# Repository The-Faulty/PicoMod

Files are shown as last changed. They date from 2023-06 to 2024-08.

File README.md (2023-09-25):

# PicoMod
PicoMod is an RP2040-based compute module with high density connectors allowing for its small 20mmx20mm form-factor.

# PicoMod Breakout
This is a breakout for PicoMod to allowing use on a standard breadboard.

# PicoMod Eject
Eject is the evolution of [Lyra](https://github.com/The_Faulty/Lyra) maintaining Lyra's small size while greatly improving the power and sensing abilities. Not only can eject ignite an e-match at apogee, it also contains a 9-DOF sensor suite and two servo outputs enabling TVC (thrust vector control) usage.

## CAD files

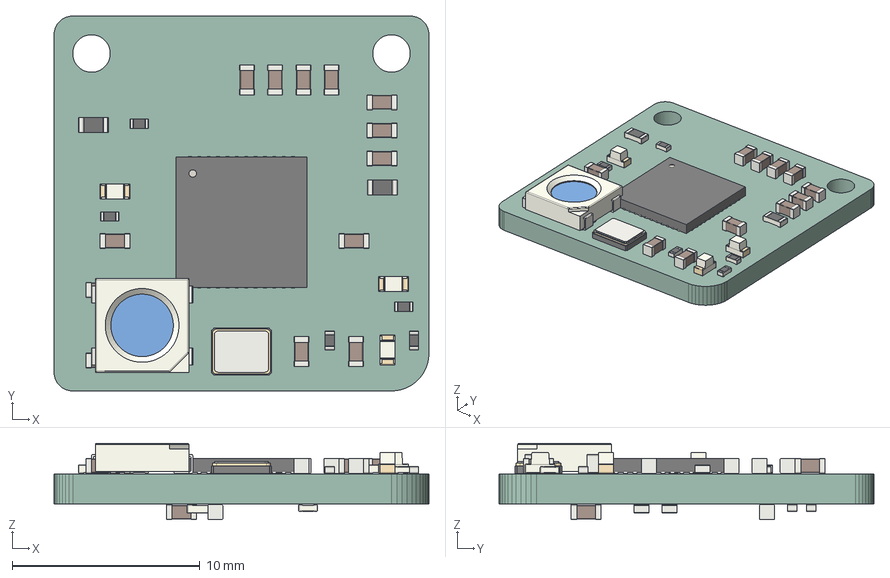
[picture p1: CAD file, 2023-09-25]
PicoMod Core/PicoMod.step
20.0 x 20.0 x 4.08 mm
PicoMod PCB

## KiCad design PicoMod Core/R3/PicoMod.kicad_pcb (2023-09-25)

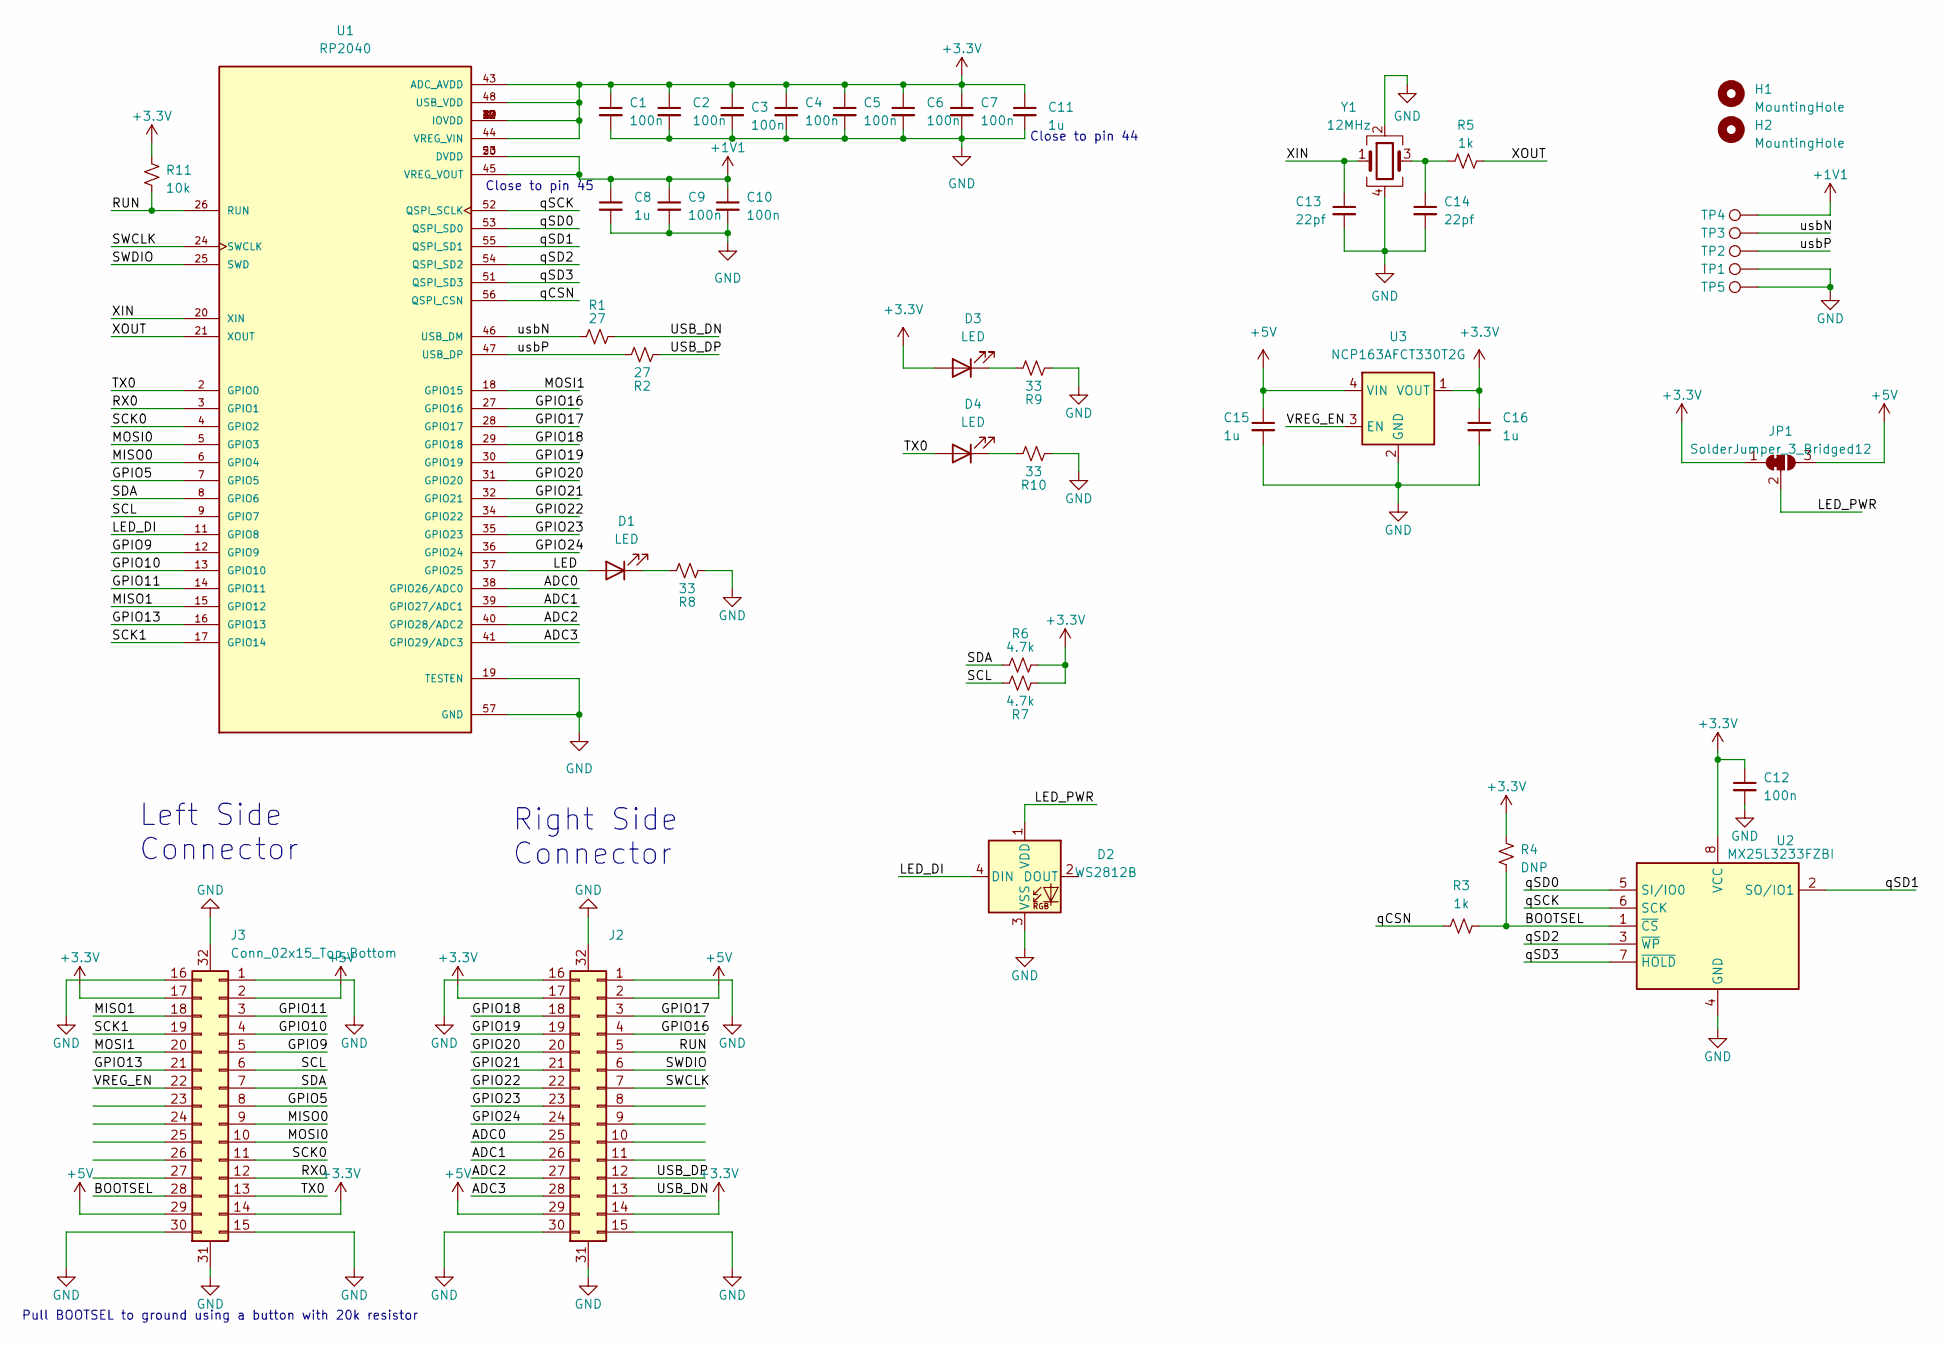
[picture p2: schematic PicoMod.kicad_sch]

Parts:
C1, C2, C3, C4, C5, C6, C7, C9, C10, C12: 100n; C_0603_1608Metric
C8, C11, C15, C16: 1u; C_0603_1608Metric
C13, C14: 22pf; C_0603_1608Metric
D1, D3, D4: LED; LED_0603_1608Metric
D2: WS2812B; LED_WS2812B_PLCC4_2.0x2.0mm_P0.4mm
H1, H2: MountingHole; MountingHole_2mm_M2
J2, J3: Conn_02x15_Top_Bottom; TE-3-2363962-0_30x0.4mm_Plug
JP1: SolderJumper_3_Bridged12; SolderJumper-3_P1.3mm_Open_RoundedPad1.0x1.5mm
R1, R2: 27; R_0402_1005Metric
R3, R5: 1k; R_0402_1005Metric
R4: DNP; R_0603_1608Metric
R6, R7: 4.7k; R_0603_1608Metric
R8, R9, R10: 33; R_0402_1005Metric
R11: 10k; R_0603_1608Metric
TP1: TestPoint; TestPoint_Loop_1.6x0.8mm
TP2, TP3, TP4, TP5: TestPoint; TestPoint_Pad_D1.0mm
U1: RP2040; QFN40P700X700X90-57N; PARTREV 1.6.1
U2: MX25L3233FZBI; SON80P400X300X60-10N
U3: NCP163AFCT330T2G; OnSemi_XDFN4-1EP_1.0x1.0mm_EP0.52x0.52mm
Y1: 12MHz; Crystal_SMD_SeikoEpson_TSX3225-4Pin_3.2x2.5mm

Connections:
+1V1: C8.1, C9.1, C10.1, TP4.1, U1.23 (DVDD), U1.45 (VREG_VOUT), U1.50 (DVDD)
+3V3: C1.1, C2.1, C3.1, C4.1, C5.1, C6.1, C7.1, C11.1, C12.1, C16.1, D3.2 (A), J2.14, J2.17, J3.14, J3.17, JP1.1 (A), R4.2, R6.2, R7.2, R11.2, U1.1 (IOVDD), U1.10 (IOVDD), U1.22 (IOVDD), U1.33 (IOVDD), U1.42 (IOVDD), U1.43 (ADC_AVDD), U1.44 (VREG_VIN), U1.48 (USB_VDD), U1.49 (IOVDD), U2.8 (VCC), U3.1 (VOUT)
+5V: C15.1, J2.2, J2.29, J3.2, J3.29, JP1.3 (B), U3.4 (VIN)
/ADC0: J2.25, U1.38 (GPIO26/ADC0)
/ADC1: J2.26, U1.39 (GPIO27/ADC1)
/ADC2: J2.27, U1.40 (GPIO28/ADC2)
/ADC3: J2.28, U1.41 (GPIO29/ADC3)
/BOOTSEL: J3.28, R3.2, R4.1, U2.1 (~CS)
/GPIO5: J3.8, U1.7 (GPIO5)
/GPIO9: J3.5, U1.12 (GPIO9)
/GPIO10: J3.4, U1.13 (GPIO10)
/GPIO11: J3.3, U1.14 (GPIO11)
/GPIO13: J3.21, U1.16 (GPIO13)
/GPIO16: J2.4, U1.27 (GPIO16)
/GPIO17: J2.3, U1.28 (GPIO17)
/GPIO18: J2.18, U1.29 (GPIO18)
/GPIO19: J2.19, U1.30 (GPIO19)
/GPIO20: J2.20, U1.31 (GPIO20)
/GPIO21: J2.21, U1.32 (GPIO21)
/GPIO22: J2.22, U1.34 (GPIO22)
/GPIO23: J2.23, U1.35 (GPIO23)
/GPIO24: J2.24, U1.36 (GPIO24)
/LED: D1.2 (A), U1.37 (GPIO25)
/LED_DI: D2.4 (DIN), U1.11 (GPIO8)
/LED_PWR: D2.1 (VDD), JP1.2 (C)
/MISO0: J3.9, U1.6 (GPIO4)
/MISO1: J3.18, U1.15 (GPIO12)
/MOSI0: J3.10, U1.5 (GPIO3)
/MOSI1: J3.20, U1.18 (GPIO15)
/RUN: J2.5, R11.1, U1.26 (RUN)
/RX0: J3.12, U1.3 (GPIO1)
/SCK0: J3.11, U1.4 (GPIO2)
/SCK1: J3.19, U1.17 (GPIO14)
/SCL: J3.6, R7.1, U1.9 (GPIO7)
/SDA: J3.7, R6.1, U1.8 (GPIO6)
/SWCLK: J2.7, U1.24 (SWCLK)
/SWDIO: J2.6, U1.25 (SWD)
/TX0: D4.2 (A), J3.13, U1.2 (GPIO0)
/USB_DN: J2.13, R1.2
/USB_DP: J2.12, R2.2
/VREG_EN: J3.22, U3.3 (EN)
/XIN: C13.1, U1.20 (XIN), Y1.1
/XOUT: R5.1, U1.21 (XOUT)
/qCSN: R3.1, U1.56 (QSPI_CSN)
/qSCK: U1.52 (QSPI_SCLK), U2.6 (SCK)
/qSD0: U1.53 (QSPI_SD0), U2.5 (SI/IO0)
/qSD1: U1.55 (QSPI_SD1), U2.2 (SO/IO1)
/qSD2: U1.54 (QSPI_SD2), U2.3 (~WP)
/qSD3: U1.51 (QSPI_SD3), U2.7 (~HOLD)
/usbN: R1.1, TP3.1, U1.46 (USB_DM)
/usbP: R2.1, TP2.1, U1.47 (USB_DP)
GND: C1.2, C2.2, C3.2, C4.2, C5.2, C6.2, C7.2, C8.2, C9.2, C10.2, C11.2, C12.2, C13.2, C14.2, C15.2, C16.2, D2.3 (VSS), J2.1, J2.15, J2.16, J2.30, J2.31 (Pin_30), J2.32 (Pin_30), J3.1, J3.15, J3.16, J3.30, J3.31 (Pin_30), J3.32 (Pin_30), R8.2, R9.2, R10.2, TP1.1, TP5.1, U1.19 (TESTEN), U1.57 (GND), U2.4 (GND), U3.2 (GND), Y1.2, Y1.4
unnamed: C14.1, R5.2, Y1.3
unnamed: D1.1 (K), R8.1
unnamed: D3.1 (K), R9.1
unnamed: D4.1 (K), R10.1

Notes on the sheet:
Close to pin 45
Left Side Connector
Close to pin 44
Right Side Connector
Pull BOOTSEL to ground using a button with 20k resistor

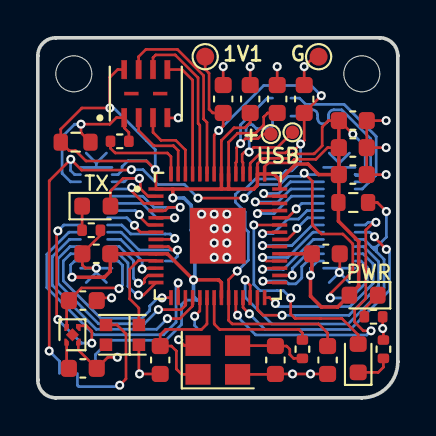
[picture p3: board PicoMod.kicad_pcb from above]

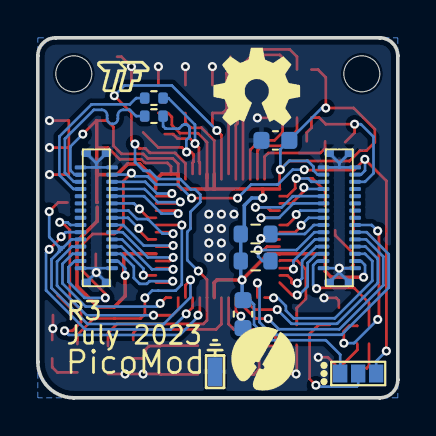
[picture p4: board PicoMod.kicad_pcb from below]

Board: 2 copper layers, 20.0 x 20.0 mm, 45 parts (10 on the bottom side), 56 nets.

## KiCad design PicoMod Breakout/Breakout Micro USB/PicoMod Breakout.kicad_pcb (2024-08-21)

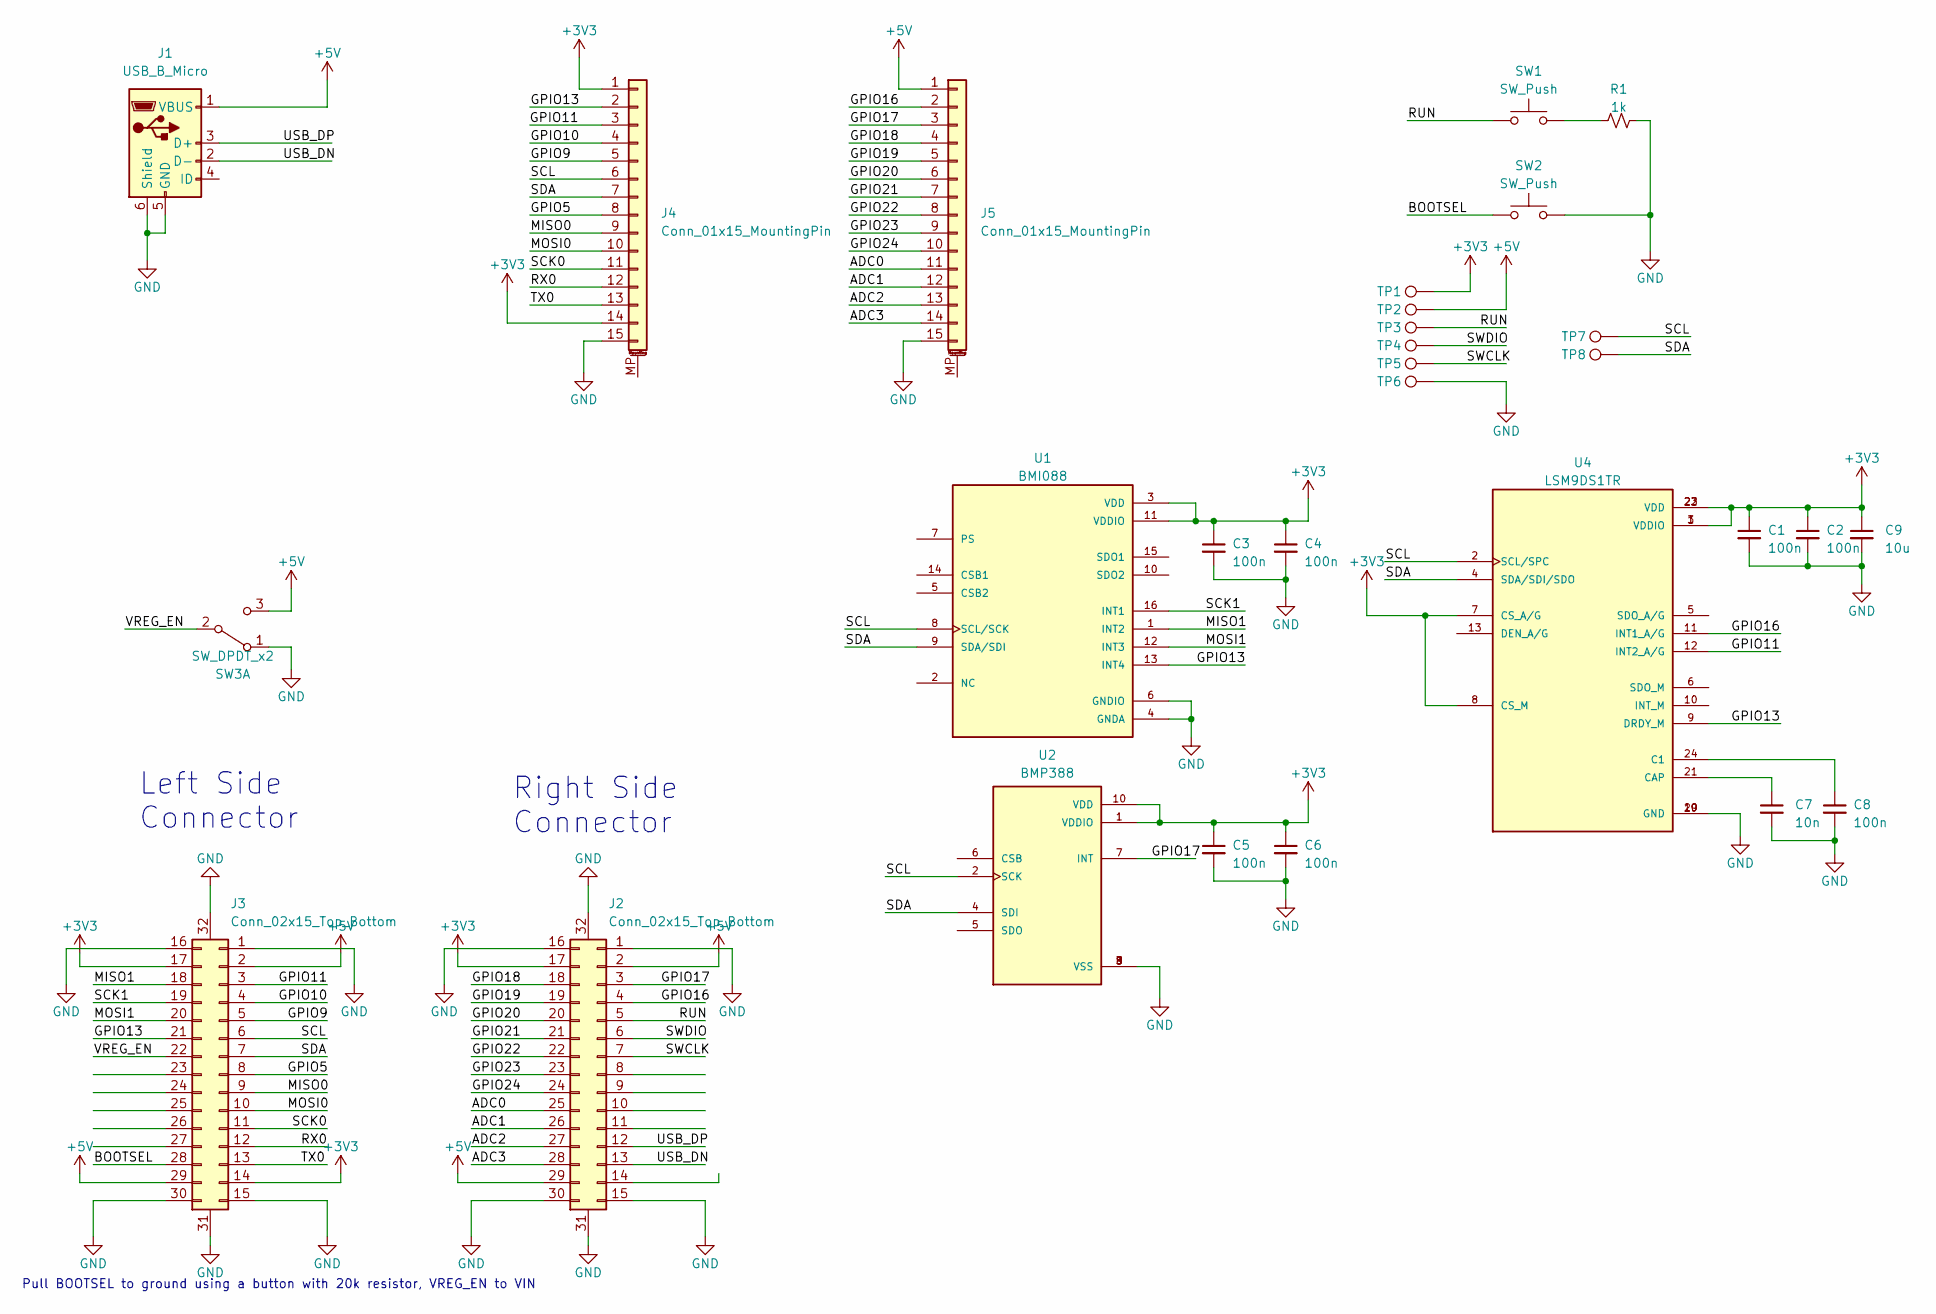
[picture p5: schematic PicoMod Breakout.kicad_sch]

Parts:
C1, C2, C3, C4, C5, C6, C8: 100n; C_0603_1608Metric
C7: 10n; C_0603_1608Metric
C9: 10u; C_0603_1608Metric
J1: USB_B_Micro; USB_Micro-B_Amphenol_10104110_Horizontal
J2, J3: Conn_02x15_Top_Bottom; TE-3-2363962-0_30x0.4mm_Recepticle
J4, J5: Conn_01x15_MountingPin; PinSocket_1x15_P2.54mm_Vertical
R1: 1k; R_0603_1608Metric_Pad0.98x0.95mm_HandSolder
SW1, SW2: SW_Push; PTS815 SJM 250
SW3: SW_DPDT_x2; SPDT_Switch_AYZ0102AGRLC
TP1, TP2, TP3, TP4, TP5, TP6, TP7, TP8: TestPoint; TestPoint_Loop_1.6x0.8mm
U1: BMI088; PQFN50P450X300X100-16N
U2: BMP388; PQFN50P200X200X80-10N; PARTREV 1.1
U4: LSM9DS1TR; PQFN43P300X350X102-24N; PARTREV 3

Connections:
+3V3: C1.1, C2.1, C3.1, C4.1, C5.1, C6.1, C9.1, J2.17, J3.14, J3.17, J4.1, J4.14, TP1.1, U1.3 (VDD), U1.11 (VDDIO), U2.1 (VDDIO), U2.10 (VDD), U4.1 (VDDIO), U4.3 (VDDIO), U4.7 (CS_A/G), U4.8 (CS_M), U4.22 (VDD), U4.23 (VDD)
+5V: J1.1 (VBUS), J2.2, J2.29, J3.2, J3.29, J5.1, SW3.3 (C), TP2.1
/ADC0: J2.25, J5.11
/ADC1: J2.26, J5.12
/ADC2: J2.27, J5.13
/ADC3: J2.28, J5.14
/BOOTSEL: J3.28, SW2.1
/GPIO5: J3.8, J4.8
/GPIO9: J3.5, J4.5
/GPIO10: J3.4, J4.4
/GPIO11: J3.3, J4.3, U4.12 (INT2_A/G)
/GPIO13: J3.21, J4.2, U1.13 (INT4), U4.9 (DRDY_M)
/GPIO16: J2.4, J5.2, U4.11 (INT1_A/G)
/GPIO17: J2.3, J5.3, U2.7 (INT)
/GPIO18: J2.18, J5.4
/GPIO19: J2.19, J5.5
/GPIO20: J2.20, J5.6
/GPIO21: J2.21, J5.7
/GPIO22: J2.22, J5.8
/GPIO23: J2.23, J5.9
/GPIO24: J2.24, J5.10
/MISO0: J3.9, J4.9
/MISO1: J3.18, U1.1 (INT2)
/MOSI0: J3.10, J4.10
/MOSI1: J3.20, U1.12 (INT3)
/RUN: J2.5, SW1.1, TP3.1
/RX0: J3.12, J4.12
/SCK0: J3.11, J4.11
/SCK1: J3.19, U1.16 (INT1)
/SCL: J3.6, J4.6, TP7.1, U1.8 (SCL/SCK), U2.2 (SCK), U4.2 (SCL/SPC)
/SDA: J3.7, J4.7, TP8.1, U1.9 (SDA/SDI), U2.4 (SDI), U4.4 (SDA/SDI/SDO)
/SWCLK: J2.7, TP5.1
/SWDIO: J2.6, TP4.1
/TX0: J3.13, J4.13
/USB_DN: J1.2 (D-), J2.13
/USB_DP: J1.3 (D+), J2.12
/VREG_EN: J3.22, SW3.2 (B)
GND: C1.2, C2.2, C3.2, C4.2, C5.2, C6.2, C7.2, C8.2, C9.2, J1.5 (GND), J1.6 (Shield), J2.1, J2.15, J2.16, J2.30, J2.31 (Pin_30), J2.32 (Pin_30), J3.1, J3.15, J3.16, J3.30, J3.31 (Pin_30), J3.32 (Pin_30), J4.15, J5.15, R1.2, SW2.2, SW3.1 (A), TP6.1, U1.4 (GNDA), U1.6 (GNDIO), U2.3 (VSS), U2.8 (VSS), U2.9 (VSS), U4.19 (GND), U4.20 (GND)
unnamed: R1.1, SW1.2
unnamed: C8.1, U4.24 (C1)
unnamed: C7.1, U4.21 (CAP)

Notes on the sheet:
Left Side Connector
Right Side Connector
Pull BOOTSEL to ground using a button with 20k resistor, VREG_EN to VIN

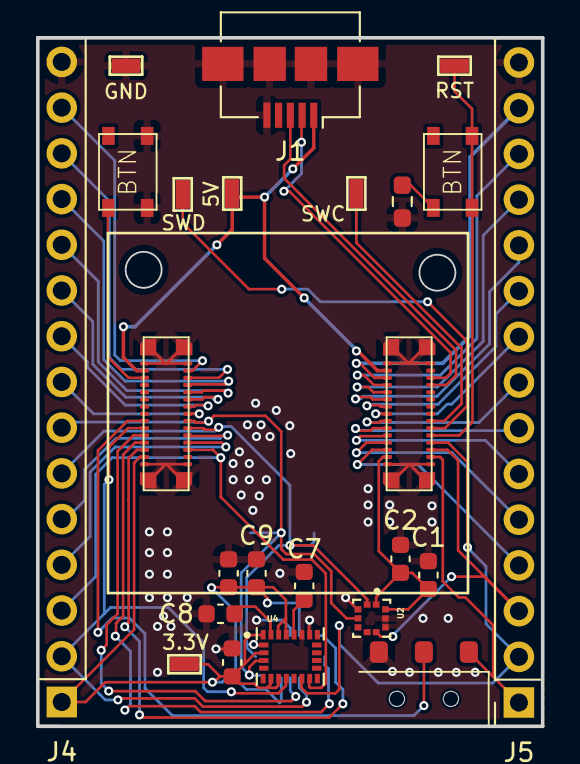
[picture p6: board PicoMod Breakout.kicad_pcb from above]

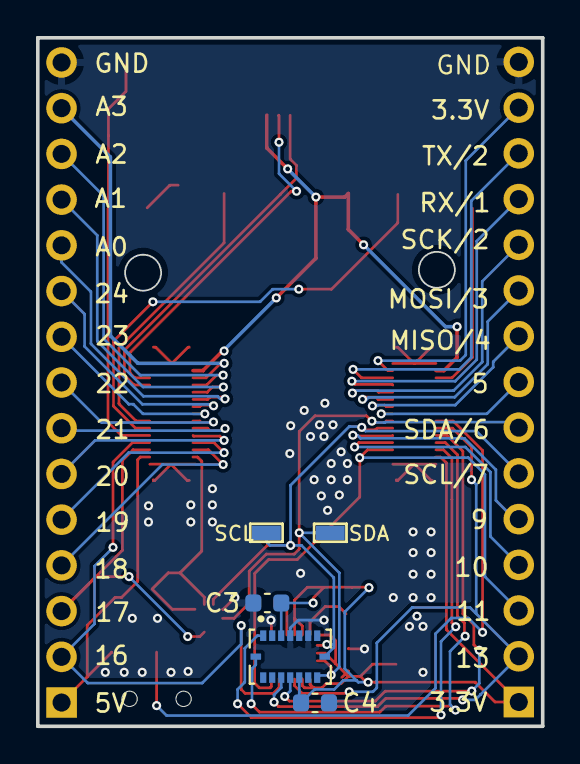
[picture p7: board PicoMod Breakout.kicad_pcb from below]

Board: 2 copper layers, 28.0 x 38.3 mm, 29 parts (5 on the bottom side), 41 nets.

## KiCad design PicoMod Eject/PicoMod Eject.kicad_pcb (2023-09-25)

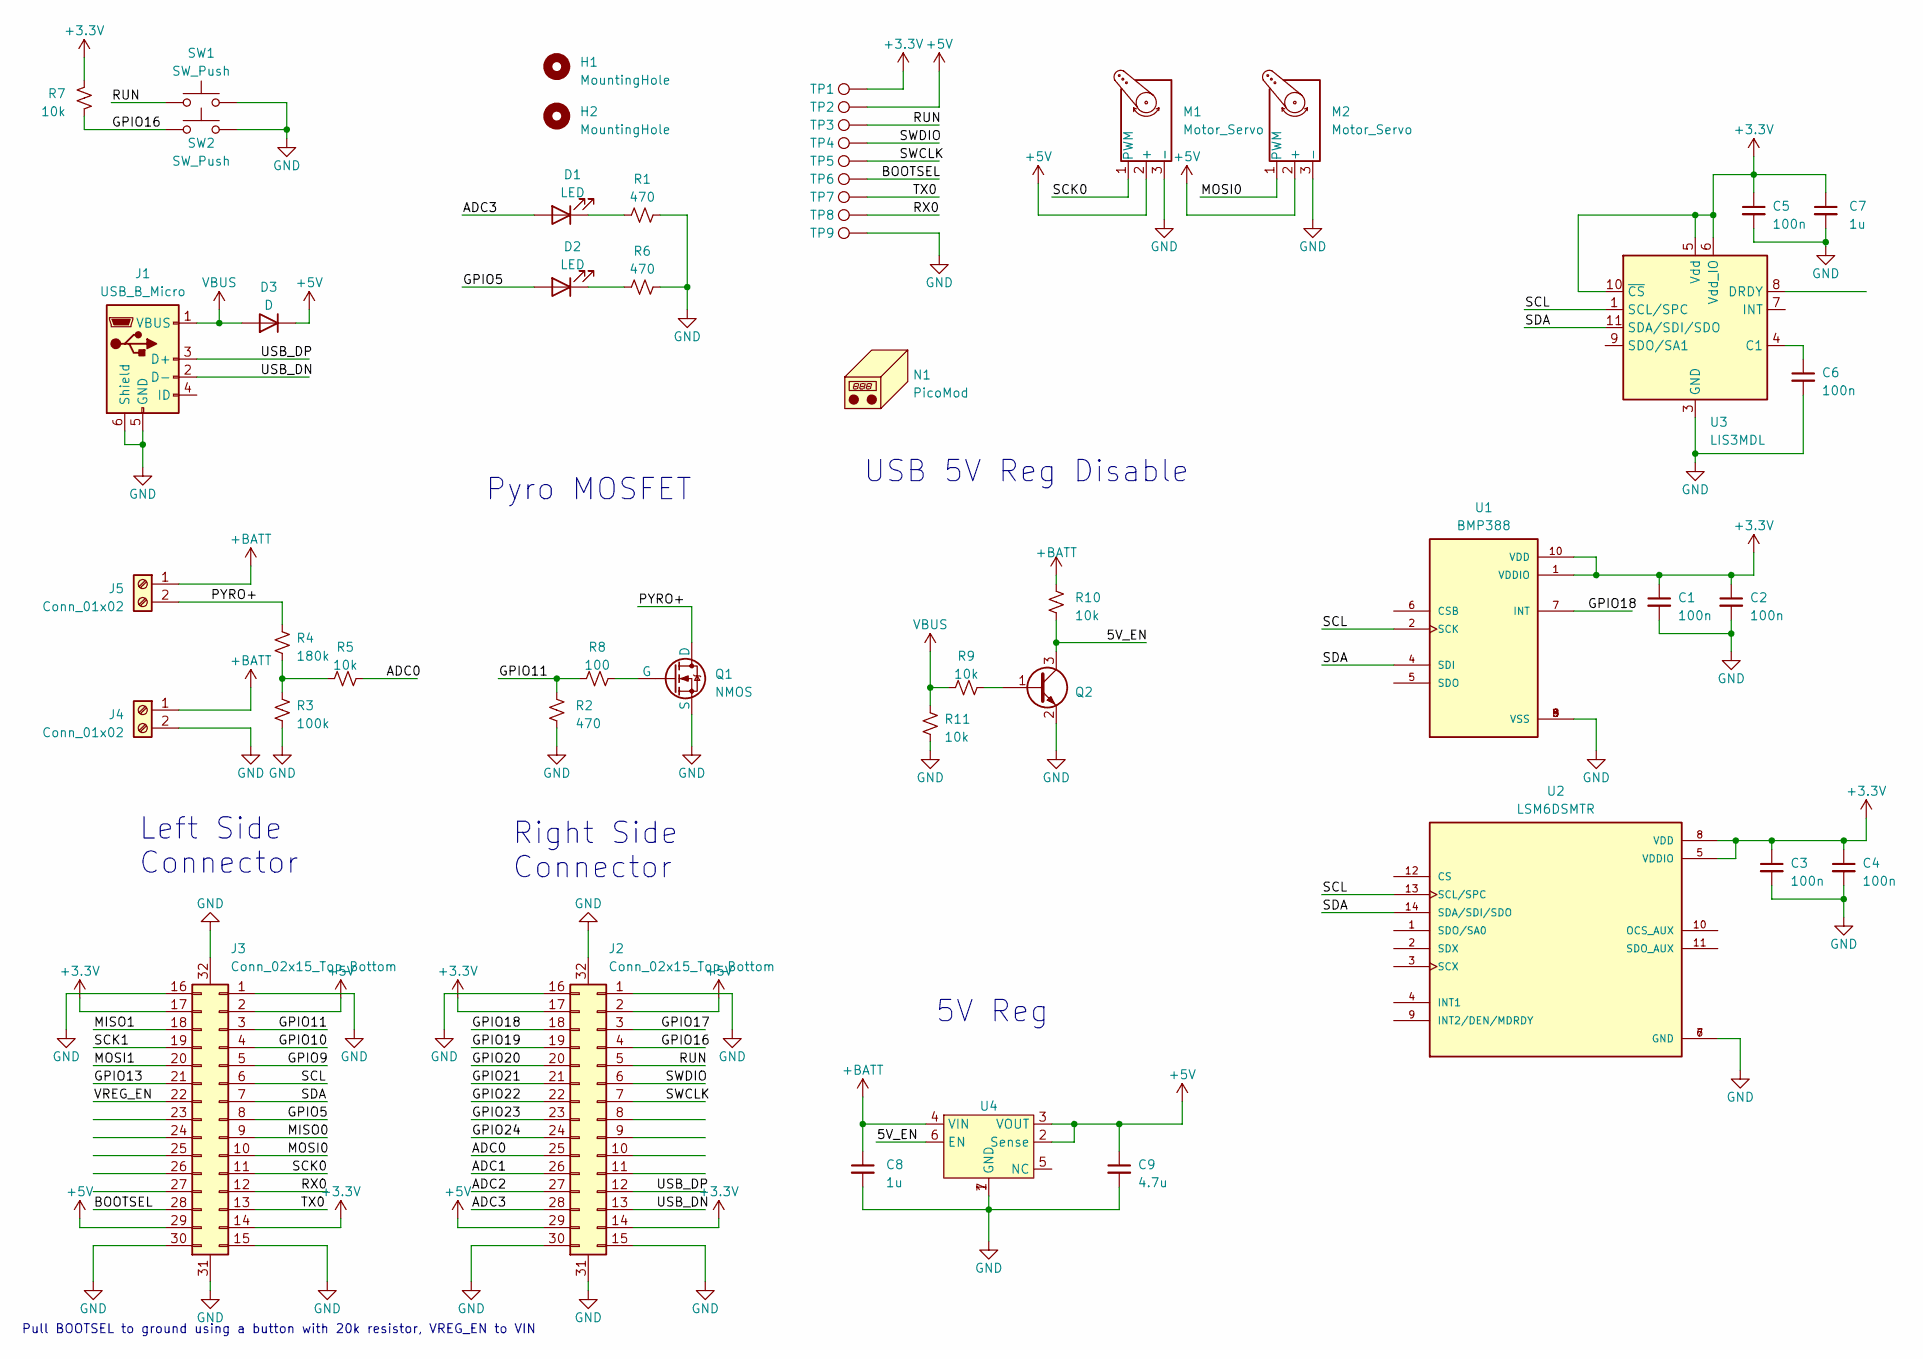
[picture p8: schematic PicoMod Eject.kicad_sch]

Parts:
C1, C2, C3, C4, C5, C6: 100n; C_0603_1608Metric
C7, C8: 1u; C_0603_1608Metric
C9: 4.7u; C_0603_1608Metric
D1, D2: LED; LED_0603_1608Metric
D3: D; D_SOD-523
H1, H2: MountingHole; MountingHole_2mm_M2
J1: USB_B_Micro; USB_Micro-B_Amphenol_10104110_Horizontal
J2, J3: Conn_02x15_Top_Bottom; TE-3-2363962-0_30x0.4mm_Recepticle
J4, J5: Conn_01x02; TerminalBlock_TE_282834-2_1x02_P2.54mm_Horizontal
M1, M2: Motor_Servo; 1x3-Servo-Connector-1.2x2mm
N1: PicoMod; OSHW-Logo_7.5x8mm_SilkScreen
Q1: NMOS; MOSFET_SI8406DB-T2-E1
Q2: SOT-323_SC-70
R1, R6: 470; R_0402_1005Metric
R2: 470; R_0603_1608Metric_Pad0.98x0.95mm_HandSolder
R3: 100k; R_0402_1005Metric_Pad0.72x0.64mm_HandSolder
R4: 180k; R_0402_1005Metric_Pad0.72x0.64mm_HandSolder
R5, R9, R11: 10k; R_0603_1608Metric_Pad0.98x0.95mm_HandSolder
R7, R10: 10k; R_0603_1608Metric
R8: 100; R_0603_1608Metric_Pad0.98x0.95mm_HandSolder
SW1, SW2: SW_Push; PTS815 SJM 250
TP1, TP2, TP3, TP4, TP5, TP6, TP7, TP8, TP9: TestPoint; TestPoint_Loop_1.6x0.8mm
U1: BMP388; PQFN50P200X200X80-10N; PARTREV 1.1
U2: LSM6DSMTR; PQFN50P300X250X86-14N; PARTREV Rev 7
U3: LIS3MDL; LGA-12_2x2mm_P0.5mm
U4: LDL212PU-5V-Regulator

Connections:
+3V3: C1.1, C2.1, C3.1, C4.1, C5.1, C7.1, J2.14, J2.17, J3.14, J3.17, R7.1, TP1.1, U1.1 (VDDIO), U1.10 (VDD), U2.5 (VDDIO), U2.8 (VDD), U3.5 (Vdd), U3.6 (Vdd_IO), U3.10 (~CS)
+5V: C9.1, D3.1 (K), J2.2, J2.29, J3.2, J3.29, M1.2 (+), M2.2 (+), TP2.1, U4.2 (Sense), U4.3 (VOUT)
+BATT: C8.1, J4.1, J5.1, R10.2, U4.4 (VIN)
/5V_EN: Q2.3 (C), R10.1, U4.6 (EN)
/ADC0: J2.25, R5.1
/ADC1: J2.26
/ADC2: J2.27
/ADC3: D1.2 (A), J2.28
/BOOTSEL: J3.28, TP6.1
/GPIO5: D2.2 (A), J3.8
/GPIO9: J3.5
/GPIO10: J3.4
/GPIO11: J3.3, R2.2, R8.2
/GPIO13: J3.21
/GPIO16: J2.4, R7.2, SW2.1
/GPIO17: J2.3
/GPIO18: J2.18, U1.7 (INT)
/GPIO19: J2.19
/GPIO20: J2.20
/GPIO21: J2.21
/GPIO22: J2.22
/GPIO23: J2.23
/GPIO24: J2.24
/MISO0: J3.9
/MISO1: J3.18
/MOSI0: J3.10, M2.1 (PWM)
/MOSI1: J3.20
/PYRO+: J5.2, Q1.1 (D), R4.2
/RUN: J2.5, SW1.1, TP3.1
/RX0: J3.12, TP8.1
/SCK0: J3.11, M1.1 (PWM)
/SCK1: J3.19
/SCL: J3.6, U1.2 (SCK), U2.13 (SCL/SPC), U3.1 (SCL/SPC)
/SDA: J3.7, U1.4 (SDI), U2.14 (SDA/SDI/SDO), U3.11 (SDA/SDI/SDO)
/SWCLK: J2.7, TP5.1
/SWDIO: J2.6, TP4.1
/TX0: J3.13, TP7.1
/USB_DN: J1.2 (D-), J2.13
/USB_DP: J1.3 (D+), J2.12
/VREG_EN: J3.22
GND: C1.2, C2.2, C3.2, C4.2, C5.2, C6.2, C7.2, C8.2, C9.2, J1.5 (GND), J1.6 (Shield), J2.1, J2.15, J2.16, J2.30, J2.31 (Pin_30), J2.32 (Pin_30), J3.1, J3.15, J3.16, J3.30, J3.31 (Pin_30), J3.32 (Pin_30), J4.2, M1.3 (-), M2.3 (-), Q1.3 (S), Q2.2 (E), R1.1, R2.1, R3.1, R6.1, R11.2, SW1.2, SW2.2, TP9.1, U1.3 (VSS), U1.8 (VSS), U1.9 (VSS), U2.6 (GND), U2.7 (GND), U3.2 (GND), U3.3 (GND), U3.12 (GND), U4.1 (GND), U4.7 (GND)
unnamed: D1.1 (K), R1.2
unnamed: D2.1 (K), R6.2
unnamed: Q1.2 (G), R8.1
unnamed: Q2.1 (B), R9.1
unnamed: R3.2, R4.1, R5.2
unnamed: C6.1, U3.4 (C1)
VBUS: D3.2 (A), J1.1 (VBUS), R9.2, R11.1

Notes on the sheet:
Left Side Connector
USB 5V Reg Disable
Pyro MOSFET
Right Side Connector
5V Reg
Pull BOOTSEL to ground using a button with 20k resistor, VREG_EN to VIN

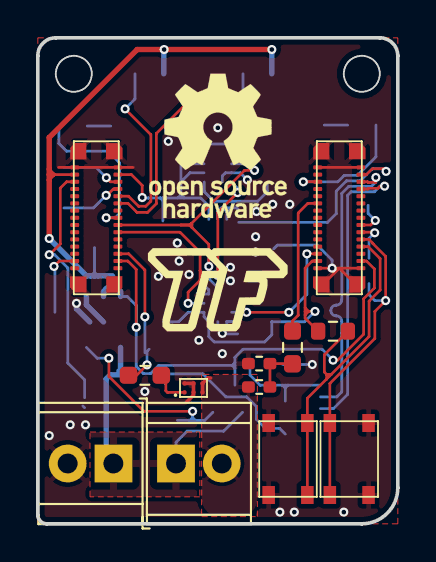
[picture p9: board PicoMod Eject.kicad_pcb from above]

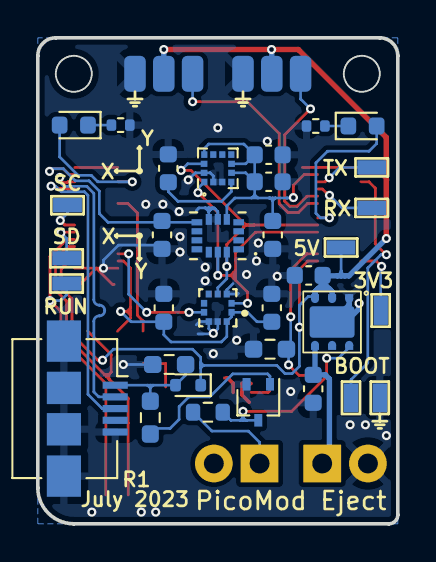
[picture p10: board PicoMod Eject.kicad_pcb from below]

Board: 2 copper layers, 20.0 x 27.0 mm, 50 parts (35 on the bottom side), 31 nets.

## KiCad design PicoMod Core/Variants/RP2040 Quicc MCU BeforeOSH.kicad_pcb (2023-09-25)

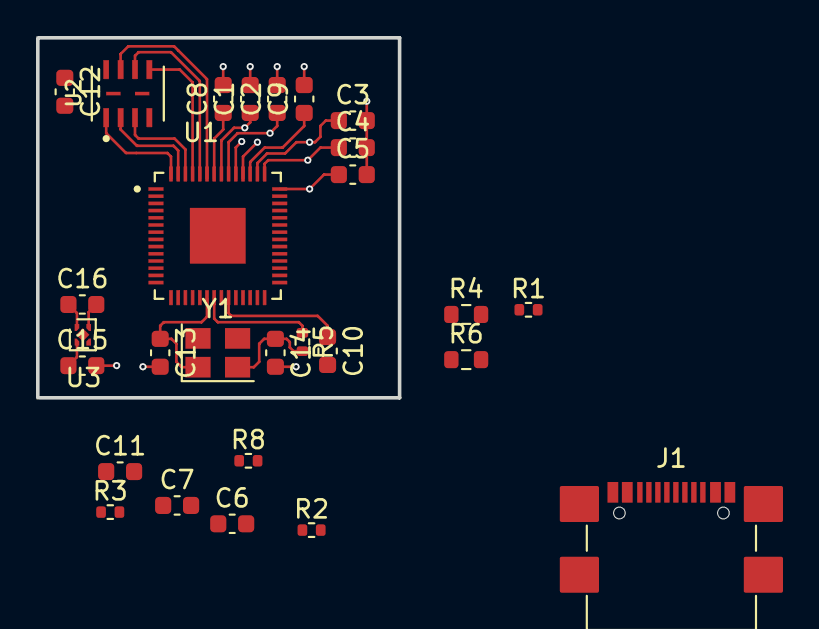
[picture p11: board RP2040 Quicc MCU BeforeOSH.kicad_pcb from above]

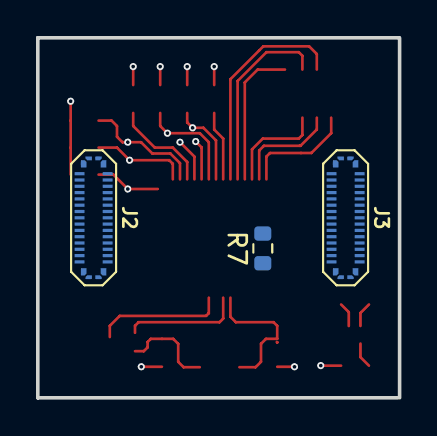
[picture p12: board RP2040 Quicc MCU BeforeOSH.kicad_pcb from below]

Board: 2 copper layers, 20.1 x 20.0 mm, 31 parts (3 on the bottom side), 19 nets.

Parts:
C1, C2, C3, C4, C5, C6, C7, C9, C10, C12: 100n; C_0603_1608Metric
C8, C11, C15, C16: 1u; C_0603_1608Metric
C13, C14: 22pf; C_0603_1608Metric
J1: USB_C_Receptacle_USB2.0; USB_C_Receptacle_GCT_USB4110
J2, J3: Conn_02x15_Top_Bottom; 245861030004829+
R1, R2, R8: 27.4; R_0402_1005Metric
R3, R5: 1k; R_0402_1005Metric
R4: 10k; R_0603_1608Metric
R6, R7: 4.7k; R_0603_1608Metric
U1: RP2040; QFN40P700X700X90-57N
U2: locked; SON80P400X300X60-10N
U3: NCP163AFCT330T2G; OnSemi_XDFN4-1EP_1.0x1.0mm_EP0.52x0.52mm
Y1: 12MHz; Crystal_SMD_SeikoEpson_TSX3225-4Pin_3.2x2.5mm

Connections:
+3V3: C1.1, C2.1, C3.1, C4.1, C5.1, C6.1, C7.1, C11.1, C12.1, C16.1, R4.2, U1.1 (IOVDD), U1.10 (IOVDD), U1.22 (IOVDD), U1.33 (IOVDD), U1.42 (IOVDD), U1.43 (ADC_AVDD), U1.44 (VREG_VIN), U1.48 (USB_VDD), U1.49 (IOVDD), U2.8 (VCC), U3.1 (VOUT)
+5V: C15.1, J1.A4 (VBUS), J1.A9 (VBUS), J1.B4 (VBUS), J1.B9 (VBUS), U3.4 (VIN)
/USB_DM: J1.A7 (D-), J1.B7 (D-), R1.2
/USB_DP: J1.A6 (D+), J1.B6 (D+), R2.2
/XIN: C13.1, U1.20 (XIN), Y1.1
/XOUT: R5.1, U1.21 (XOUT)
/qCSN: R3.2, R4.1, U1.56 (QSPI_CSN), U2.1 (~CS)
/qSCK: U1.52 (QSPI_SCLK), U2.6 (SCK)
/qSD0: U1.53 (QSPI_SD0), U2.5 (SI/IO0)
/qSD1: U1.55 (QSPI_SD1), U2.2 (SO/IO1)
/qSD2: U1.54 (QSPI_SD2), U2.3 (~WP)
/qSD3: U1.51 (QSPI_SD3), U2.7 (~HOLD)
GND: C1.2, C2.2, C3.2, C4.2, C5.2, C6.2, C7.2, C8.2, C9.2, C10.2, C11.2, C12.2, C13.2, C14.2, C15.2, C16.2, J1.A1 (GND), J1.A12 (GND), J1.B1 (GND), J1.B12 (GND), J1.S1 (SHIELD), U1.19 (TESTEN), U1.57 (GND), U2.4 (GND), U3.2 (GND)
unnamed: C8.1, C9.1, C10.1, U1.23 (DVDD), U1.45 (VREG_VOUT), U1.50 (DVDD)
unnamed: C14.1, R5.2, Y1.2
unnamed: R1.1, U1.46 (USB_DM)
unnamed: R2.1, U1.47 (USB_DP)
unnamed: R6.2, U1.6 (GPIO4)
unnamed: R7.2, U1.7 (GPIO5)

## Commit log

2023-06-07 R2 Upload
    [PicoMod.kicad_pcb, PicoMod.kicad_sch]
2023-09-25 Added other boards and readme
    [PicoMod Breakout.kicad_sch, PicoMod Breakout.stretch_bkup.kicad_pcb, PicoMod Eject.kicad_pcb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]
2024-08-21 Updated with R4 of core board and micro usb breakout
    [PicoMod Breakout.kicad_pcb, PicoMod Breakout.kicad_sch, PicoMod Breakout.stretch_bkup.kicad_pcb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]
